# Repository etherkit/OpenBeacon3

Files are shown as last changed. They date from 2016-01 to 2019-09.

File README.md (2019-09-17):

OpenBeacon 3
============
500 mW Si5351C-based MEPT Transmitter

Display
-------
Line 1: GPS status (internal or external antenna, number of satellites fixed), UTC time, transmission mode

Line 2: Frequency

Line 3: PA current, input voltage

Line 4: Message buffer contents

Line 5: Button functions

LEDs
----
* **D1** (red)

    Transmit<br />
    UART TX (during firmware loading)  

* **D2** (green)

    UART RX (during firmware loading)
    
* **D3** (blue)

    PA enabled

* **D5** (yellow)

    Power

User Interface
--------------
* **Tuning**

    Turn S4 rotary encoder to tune
    
* **Tuning Rate**

    Depress rotary encoder shaft momentarily to step through tuning rates. An underline cursor will indicate which frequency digit is being changed.
    
* **Change Band or Mode**

    Hold rotary encoder shaft in for 1 second to access the band and mode change menu. Turn the rotary encoder to cycle between selections. Press button S1 to change the band selection or press button S2 to change the mode selection. Press button S3 to exit this menu.

* **Configuration Menu (S1)**

    Not yet implemented
    
* **Start/Stop (S2)**

    Press button to immediately start a transmission if the transmitter is currently idle, or immediately stop a transmission if one is currently active.
    
* **TX Enb/TX Dis (S3)**

    Press button to toggle the state of recurring transmissions.

Message Buffer System
---------------------
When using the CW, QRSS, DFCW, and Hell modes, five different message buffers are available for transmission. Message Buffer 0 is a special case and consists solely of the value set in the ```callsign``` configuration variable. Message Buffers 1 through 4 can be set to any 40 character (consisting of letters, numbers, or characters ```/```, ```=```, and ```?```) user message via the configuration system. OpenBeacon 2 can be set transmit the contents of any of the five message buffers during a transmit period.

In WSPR mode, OpenBeacon 2 uses the callsign specified in the ```callsign``` configuration variable, the current Maidenhead grid square as determined from GPS (or the default value placed in the ```grid``` configuration variable if the GPS does not have a location fix), and the power level specified in the  ```dbm``` configuration variable.

Recurring Transmissions
-----------------------

Configuration
-------------
The configuration for OpenBeacon 2 is loaded via the included USB-UART bridge. To send configuration data, send OpenBeacon 2 a string consisting of the character 'W', followed by a JSON string setting the desired conifiguration variables, followed by a '@' termination character. For example:

    W{"callsign":"W1AW","default_buffer":2,"msg_mem_2":"HELLO WORLD"}@
    
Here is the list of available configuration variables:

* **default_buffer**
* **msg_mem_1**
* **msg_mem_2**
* **msg_mem_3**
* **msg_mem_4**
* **callsign**
* **grid**
* **dbm**
* **ext_gps_ant**
* **ext_pll_ref**
* **ext_pll_ref_freq**

Required Libraries
------------------
Install these library from the indicated locations before attempting to compile and upload your own firmware.

* Flash Storage [https://github.com/cmaglie/FlashStorage](https://github.com/cmaglie/FlashStorage)
* TinyGPS++ [http://arduiniana.org/libraries/tinygpsplus/](http://arduiniana.org/libraries/tinygpsplus/)
* Etherkit SSD1306 [https://github.com/etherkit/SSD1306-Arduino](https://github.com/etherkit/SSD1306-Arduino)
* Etherkit Si5351 (Library Manager)
* Etherkit JTEncode (Library Manager)
* Scheduler (Library Manager)
* ArduinoJson (Library Manager)
* SPI (Arduino Standard Library)
* Wire (Arduino Standard Library)

Updating the Firmware
---------------------
Connect OpenBeacon 2 to your PC via USB. In the Arduino IDE, select board type ```Arduino/Genuino Zero (Native USB Port)``` and the correct virtual serial port. Sketches can be uploaded to OpenBeacon 2 as if it were a standard Arduino Zero (although a custom hardware configuration is coming soon).

TODO
----
  - [ ] Internal/External Ref Osc
  - [ ] Internal/External GPS Antenna
  - [ ] Get Hell mode working

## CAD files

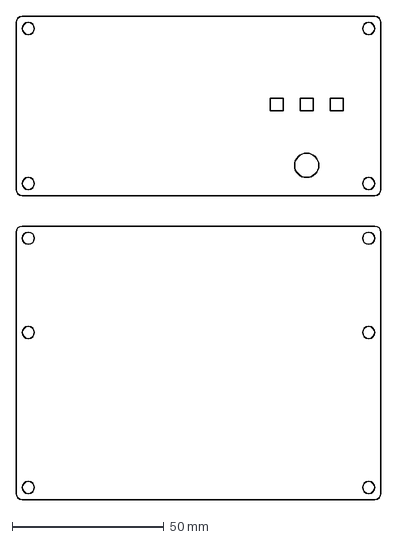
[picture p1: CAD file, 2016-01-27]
enclosure/OpenBeacon2.dxf
120.0 x 159.0 mm

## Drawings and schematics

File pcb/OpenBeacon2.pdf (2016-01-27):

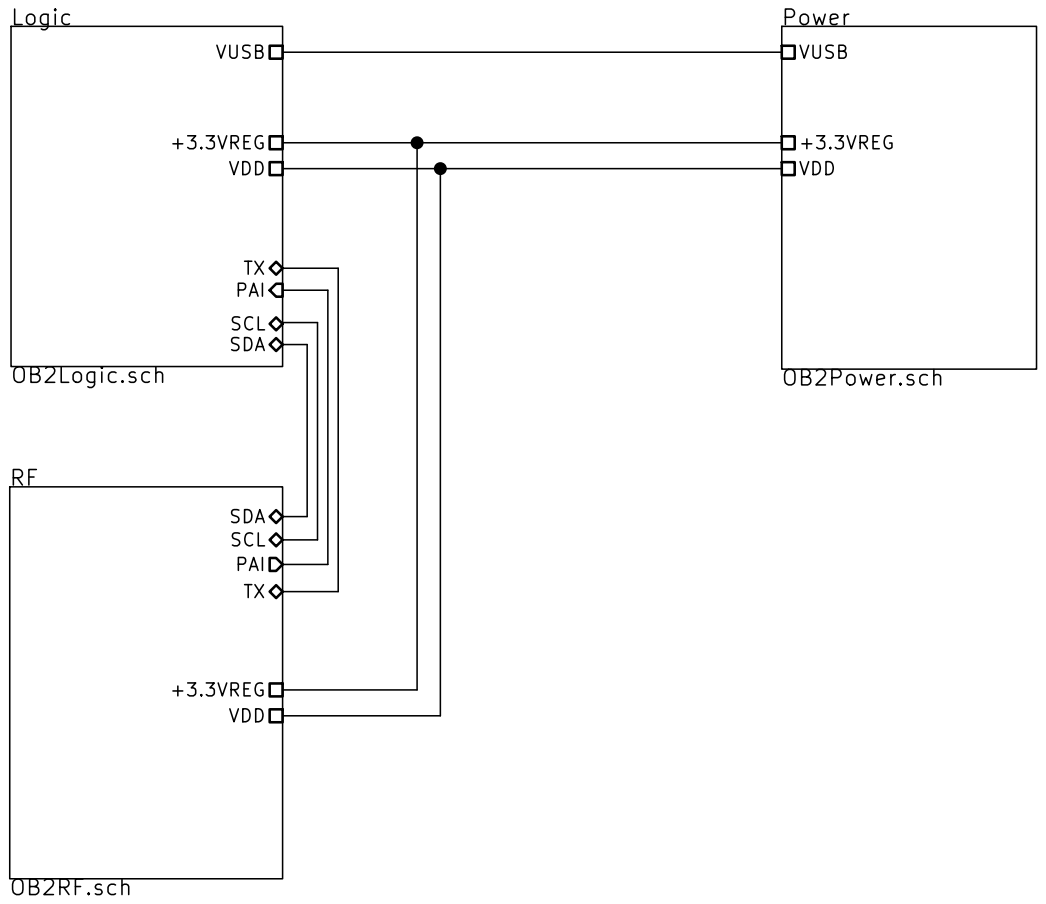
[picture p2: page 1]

File: OpenBeacon2.sch Sheet: / Etherkit Creative Commons License CC-BY-SA

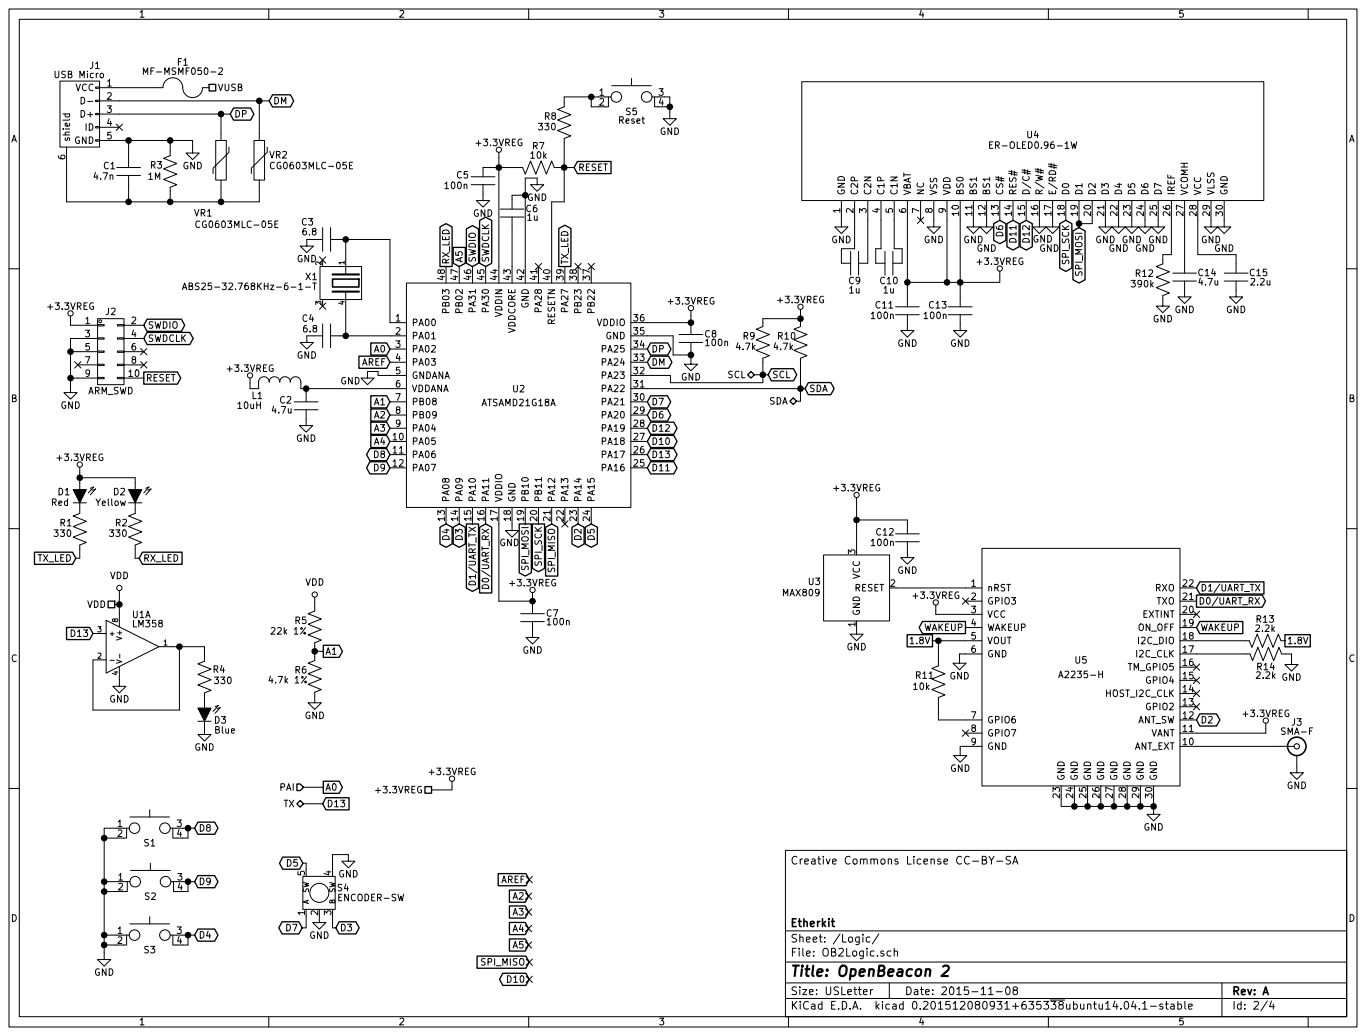
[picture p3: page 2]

9 BS0 10 D2 20 GND 30 BS1 11 D3 21 BS1 12 D4 22 CS# 13 D5 23 RES# 14 D6 24 D/C# 15 D7 25 R/W# 16 IREF 26 E/RD# 17 VCOMH 27 D0 18 VCC 28 D1 19 VLSS 29 U4 ER-OLED0.96-1W

Sheet: /Logic/ Etherkit Creative Commons License CC-BY-SA

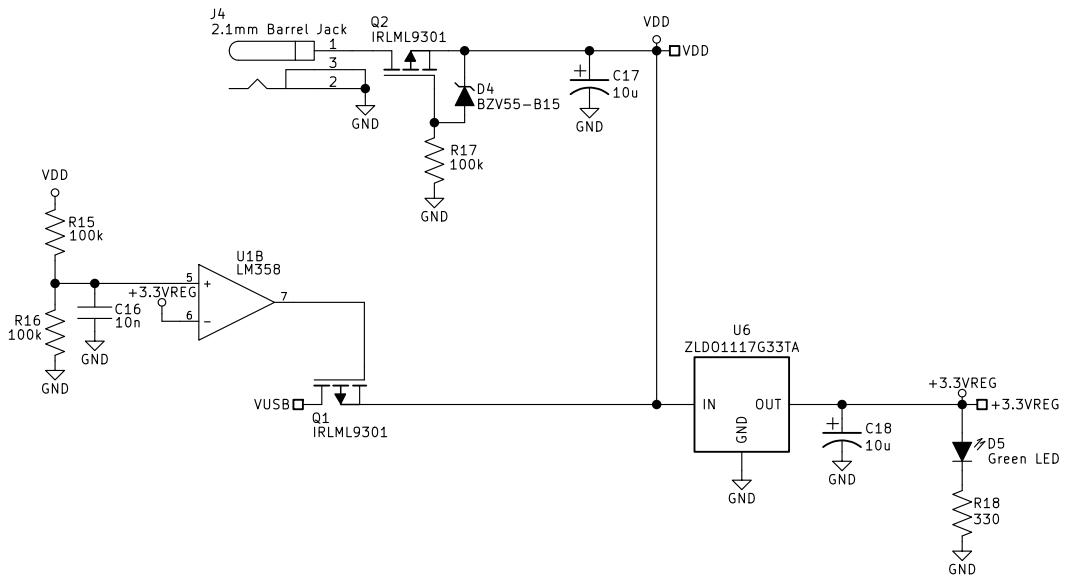
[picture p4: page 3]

File: OB2Power.sch Sheet: /Power/ Etherkit Creative Commons License CC-BY-SA

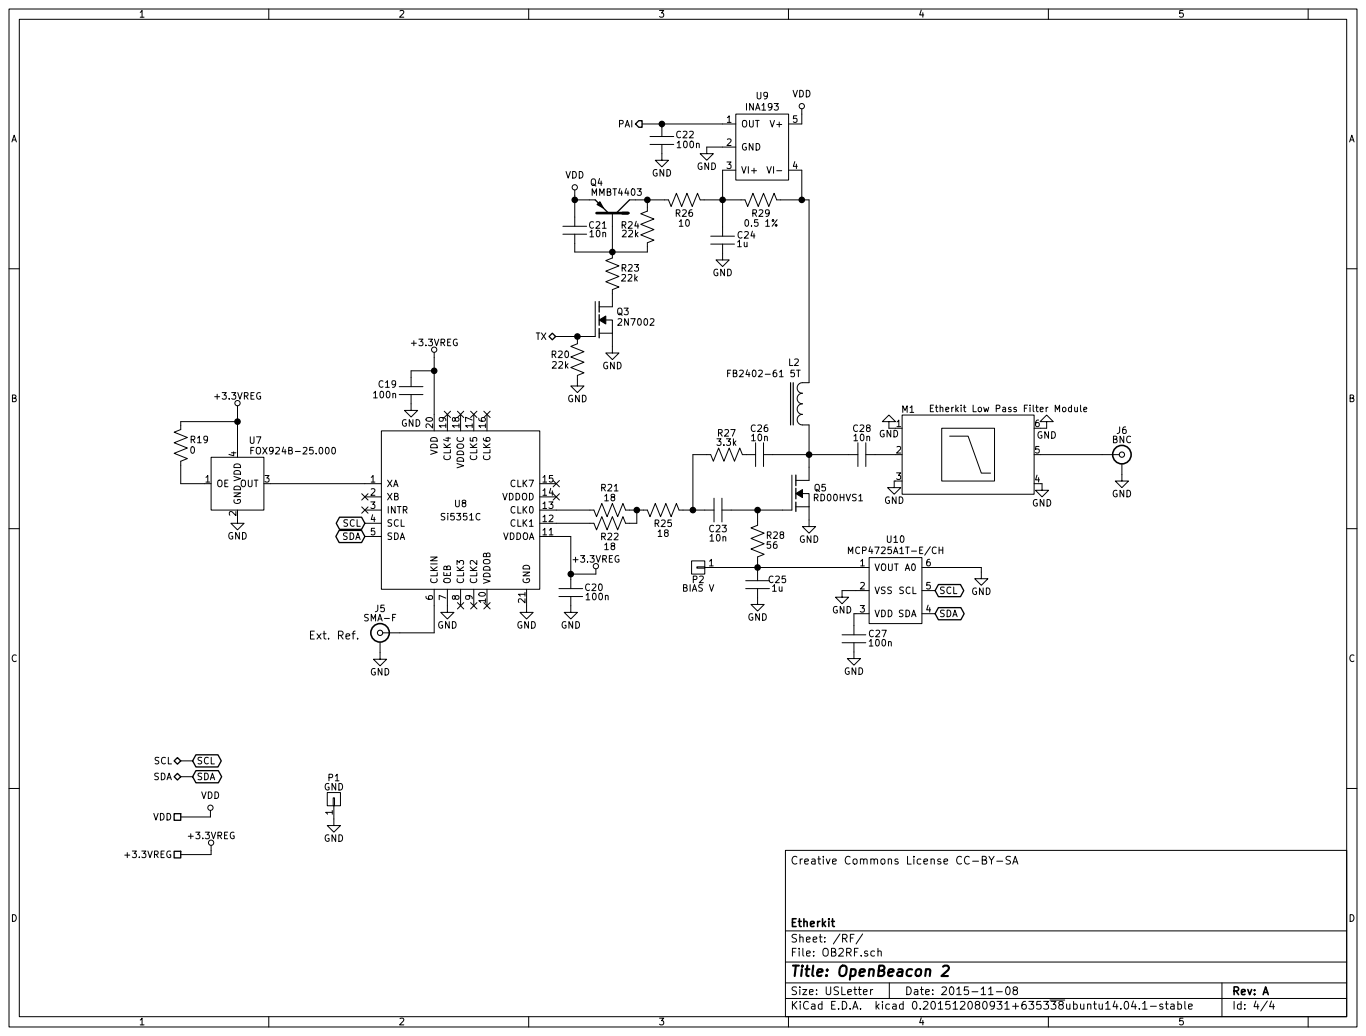
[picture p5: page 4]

9 VDDOB 10 VDD 20 VDDOA 11 GND 21 CLK1 12 CLK0 13 VDDOD 14 CLK7 15 CLK6 16 CLK5 17 VDDOC 18 CLK4 19 U8 Si5351C

File: OB2RF.sch Sheet: /RF/ Etherkit Creative Commons License CC-BY-SA

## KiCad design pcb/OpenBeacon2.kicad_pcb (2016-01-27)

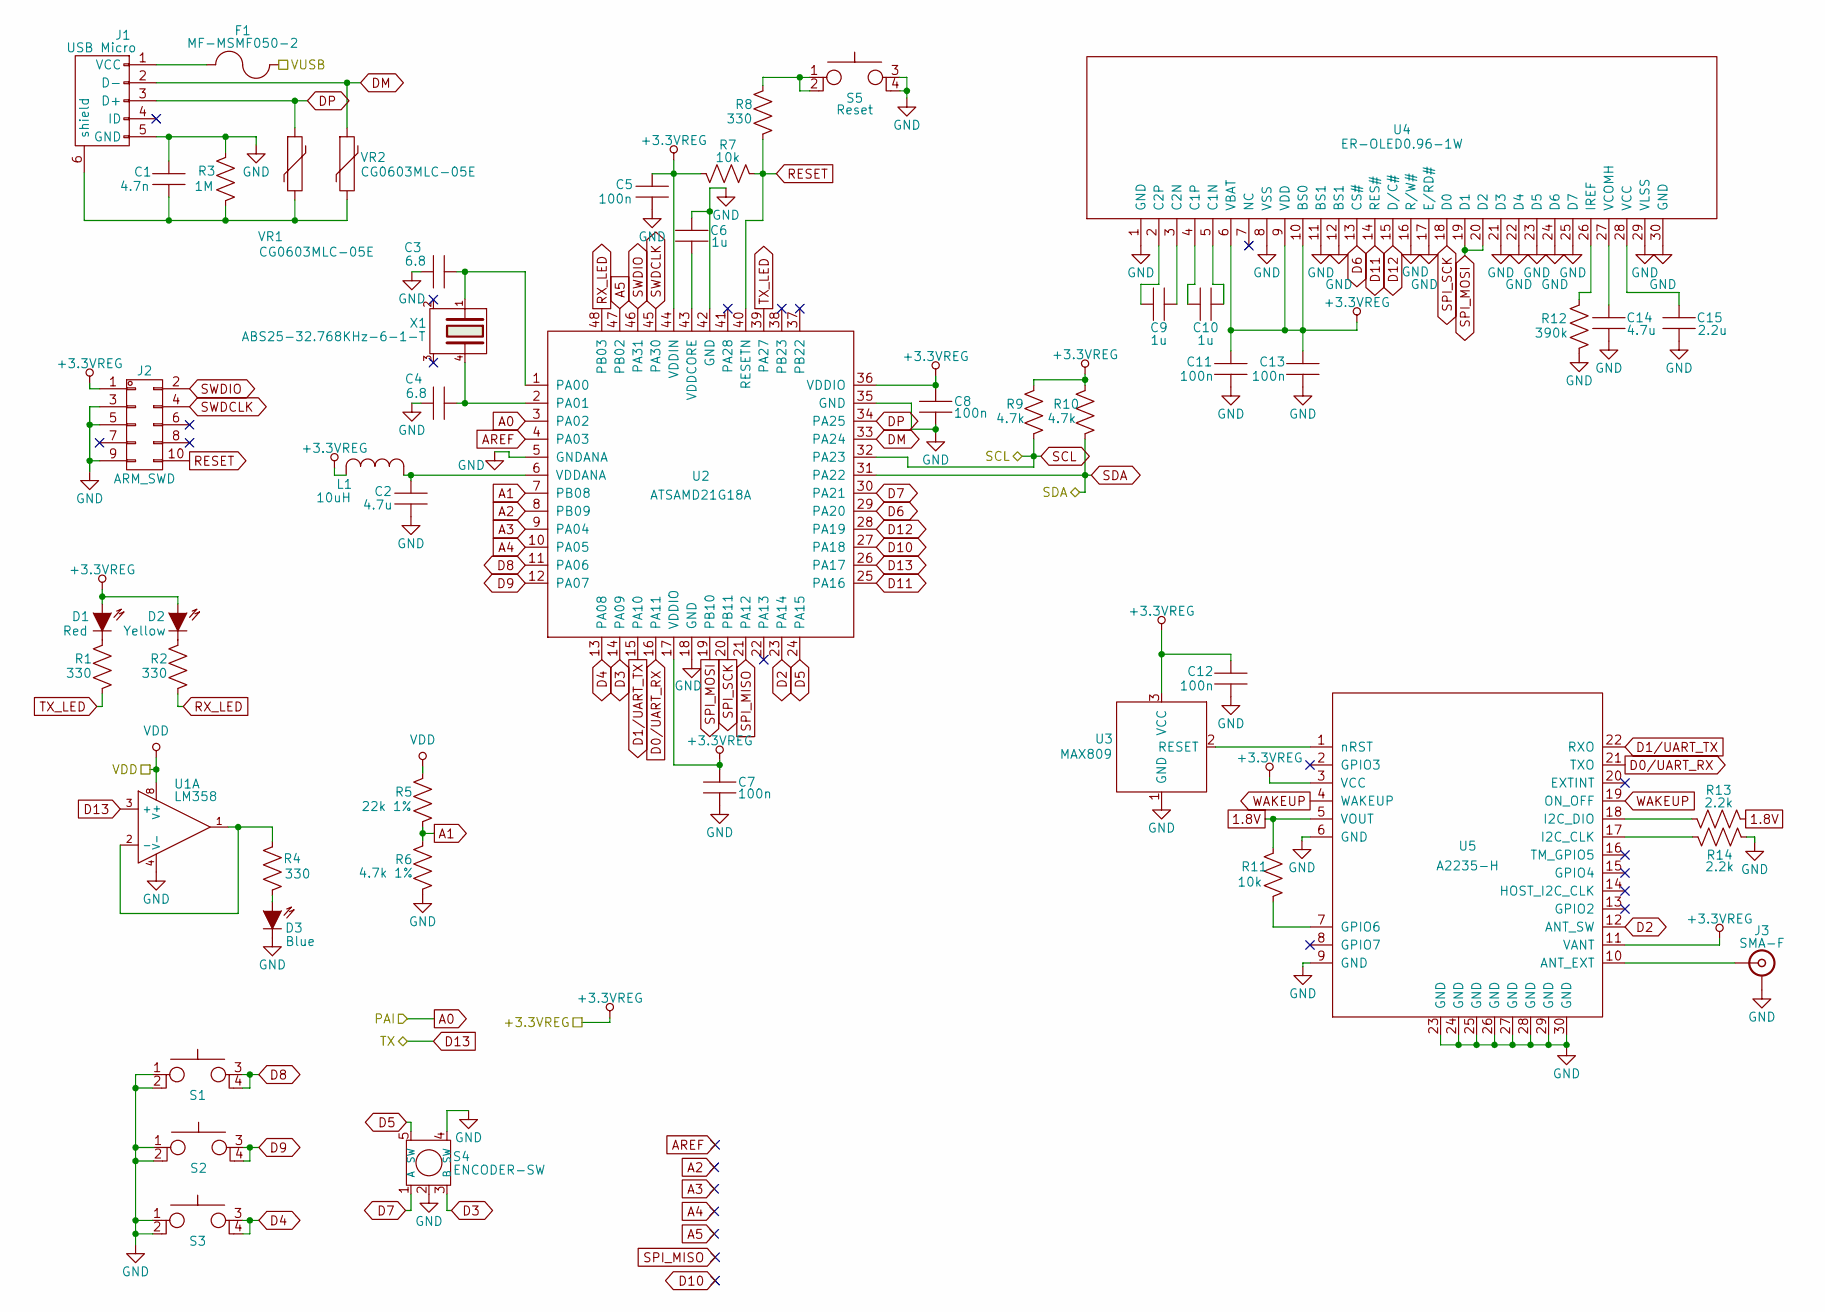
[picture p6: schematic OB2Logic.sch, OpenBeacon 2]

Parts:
C1: 4.7n; C_0805
C2, C14: 4.7u; C_0805
C3, C4: 6.8; C_0805
C5, C7, C8, C11, C12, C13: 100n; C_0805
C6, C9, C10: 1u; C_0805
C15: 2.2u; C_0805
D1: Red; Lite-On_LTST-C170
D2: Yellow; Lite-On_LTST-C170
D3: Blue; Lite-On_LTST-C170
F1: MF-MSMF050-2; Bournes_MF-MSMF050-2
J1: USB Micro; FCI_10118194-0001LF
J2: ARM_SWD; FCI_20021121-00010C4LF
J3: SMA-F; SMA-ENDLAUNCH
L1: 10uH; R_0805
R1, R2, R4, R8: 330; R_0805
R3: 1M; R_0805
R5: 22k 1%; R_0805
R6: 4.7k 1%; R_0805
R7, R11: 10k; R_0805
R9, R10: 4.7k; R_0805
R12: 390k; R_0805
R13, R14: 2.2k; R_0805
S1, S2, S3: Reset; Omron_B3F-1052
S4: ENCODER-SW; Bournes_PEC12R-4225F-S0024
S5: Reset; Alps_SKQGAKE010
U1: LM358; SOIC-8_3.9x4.9mm_Pitch1.27mm
U2: ATSAMD21G18A; TQFP-48_7x7mm_Pitch0.5mm
U3: MAX809; SOT23-MAX809
U4: ER-OLED0.96-1W; EastRising_ER-OLED0.96-1W-Thru
U5: A2235-H
VR1, VR2: CG0603MLC-05E; R_0603
X1: ABS25-32.768KHz-6-1-T; Abracon_ABS25

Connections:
1.8V: R11.1, R13.1, U5.5 (VOUT)
+3.3VREG: C5.1, C7.1, C8.1, C11.1, C12.1, C13.1, D1.1 (A), D2.1 (A), J2.1, L1.1, R7.2, R9.1, R10.1, U2.17 (VDDIO), U2.36 (VDDIO), U2.44 (VDDIN), U3.3 (VCC), U4.6 (VBAT), U4.9 (VDD), U4.10 (BS0), U5.3 (VCC), U5.11 (VANT); also elsewhere on the board
/Logic/VUSB: F1.2; also elsewhere on the board
A0: U2.3 (PA02); also elsewhere on the board
A1: R5.2, R6.1, U2.7 (PB08)
A2: U2.8 (PB09)
A3: U2.9 (PA04)
A4: U2.10 (PA05)
A5: U2.47 (PB02)
AREF: U2.4 (PA03)
D0/UART_RX: U2.16 (PA11), U5.21 (TXO)
D1/UART_TX: U2.15 (PA10), U5.22 (RXO)
D2: U2.23 (PA14), U5.12 (ANT_SW)
D3: S4.3 (B), U2.14 (PA09)
D4: S3.3, S3.4, U2.13 (PA08)
D5: S4.5 (SW), U2.24 (PA15)
D6: U2.29 (PA20), U4.13 (CS#)
D7: S4.1 (A), U2.30 (PA21)
D8: S1.3, S1.4, U2.11 (PA06)
D9: S2.3, S2.4, U2.12 (PA07)
D10: U2.27 (PA18)
D11: U2.25 (PA16), U4.14 (RES#)
D12: U2.28 (PA19), U4.15 (D/C#)
D13: U1.3 (+), U2.26 (PA17); also elsewhere on the board
DM: J1.2 (D-), U2.33 (PA24), VR2.1
DP: J1.3 (D+), U2.34 (PA25), VR1.1
GND: C1.1, C2.2, C3.1, C4.1, C5.2, C6.1, C7.2, C8.2, C11.2, C12.2, C13.2, C14.2, C15.2, D3.2 (K), J1.5 (GND), J2.3, J2.5, J2.9, J3.2 (Ext), R3.1, R6.2, R12.2, R14.1, S1.1, S1.2, S2.1, S2.2, S3.1, S3.2, S4.2, S4.4 (SW), S5.3, S5.4, U1.4 (V-), U2.5 (GNDANA), U2.18 (GND), U2.35 (GND), U2.42 (GND), U3.1 (GND), U4.1 (GND), U4.8 (VSS), U4.11 (BS1), U4.12 (BS1), U4.16 (R/W#), U4.17 (E/RD#), U4.21 (D3), U4.22 (D4), U4.23 (D5), U4.24 (D6), U4.25 (D7), U4.29 (VLSS), U4.30 (GND), U5.6 (GND), U5.9 (GND), U5.23 (GND), U5.24 (GND), U5.25 (GND), U5.26 (GND), U5.27 (GND), U5.28 (GND), U5.29 (GND), U5.30 (GND); also elsewhere on the board
unnamed: C1.2, J1.6 (shield), R3.2, VR1.2, VR2.2
unnamed: C2.1, L1.2, U2.6 (VDDANA)
unnamed: C3.2, U2.1 (PA00), X1.1
unnamed: C4.2, U2.2 (PA01), X1.4
unnamed: C6.2, U2.43 (VDDCORE)
unnamed: C9.1, U4.2 (C2P)
unnamed: C9.2, U4.3 (C2N)
unnamed: C10.1, U4.4 (C1P)
unnamed: C10.2, U4.5 (C1N)
unnamed: C14.1, U4.27 (VCOMH)
unnamed: C15.1, U4.28 (VCC)
unnamed: D1.2 (K), R1.1
unnamed: D2.2 (K), R2.1
unnamed: D3.1 (A), R4.2
unnamed: F1.1, J1.1 (VCC)
unnamed: J3.1 (In), U5.10 (ANT_EXT)
unnamed: R4.1, U1.1, U1.2 (-)
unnamed: R8.1, S5.1, S5.2
unnamed: R11.2, U5.7 (GPIO6)
unnamed: R12.1, U4.26 (IREF)
unnamed: R13.2, U5.18 (I2C_DIO)
unnamed: R14.2, U5.17 (I2C_CLK)
unnamed: U3.2 (RESET), U5.1 (nRST)
RESET: J2.10, R7.1, R8.2, U2.40 (RESETN)
RX_LED: R2.2, U2.48 (PB03)
SCL: R9.2, U2.32 (PA23); also elsewhere on the board
SDA: R10.2, U2.31 (PA22); also elsewhere on the board
SPI_MISO: U2.21 (PA12)
SPI_MOSI: U2.19 (PB10), U4.19 (D1), U4.20 (D2)
SPI_SCK: U2.20 (PB11), U4.18 (D0)
SWDCLK: J2.4, U2.45 (PA30)
SWDIO: J2.2, U2.46 (PA31)
TX_LED: R1.2, U2.39 (PA27)
VDD: R5.1, U1.8 (V+); also elsewhere on the board
WAKEUP: U5.4 (WAKEUP), U5.19 (ON_OFF)

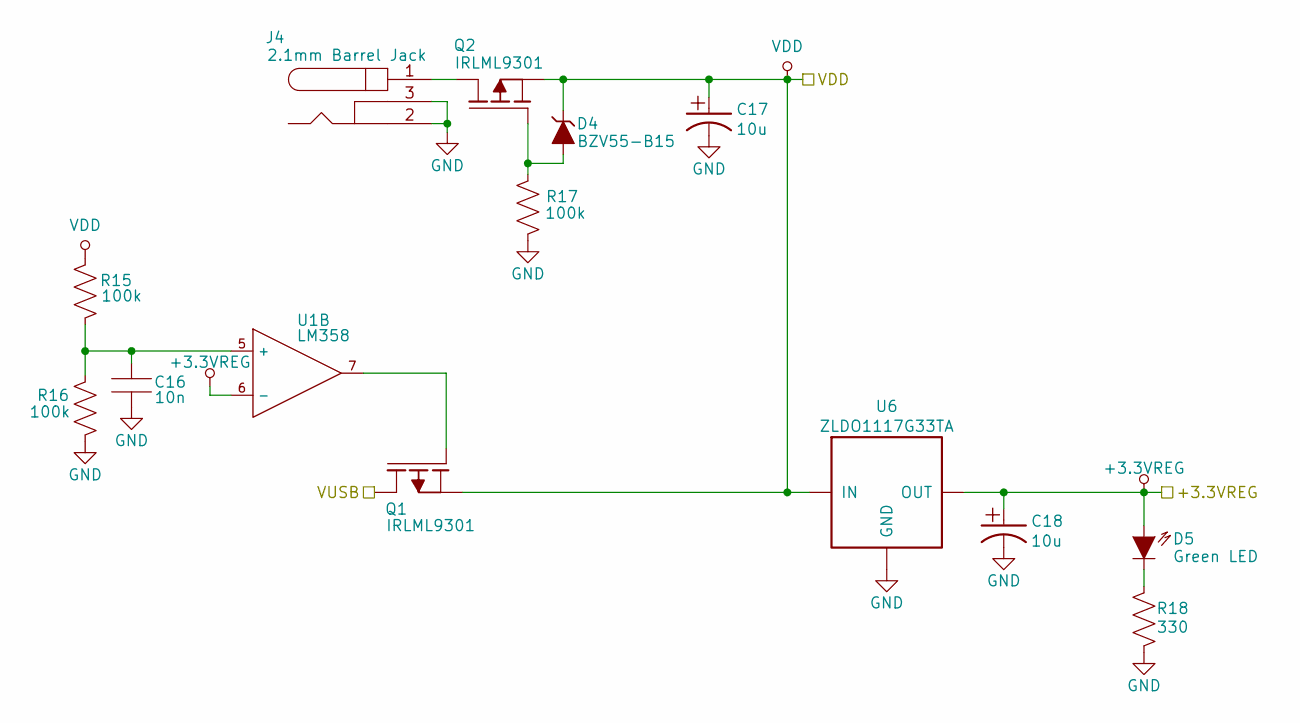
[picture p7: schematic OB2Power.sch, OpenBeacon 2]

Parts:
C16: 10n; C_0805
C17, C18: 10u; CAP-ELEC-5MM
D4: BZV55-B15; SOD80
D5: Green LED; Lite-On_LTST-C170
J4: 2.1mm Barrel Jack; DCPOWER-KOBICONN-163-7620-E
Q1, Q2: IRLML9301; SOT23-2N7002
R15, R16, R17: 100k; R_0805
R18: 330; R_0805
U1: LM358; SOIC-8_3.9x4.9mm_Pitch1.27mm
U6: ZLDO1117G33TA; SOT-223-3

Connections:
+3.3VREG: C18.1, D5.1 (A), U1.6 (-), U6.1 (OUT); also elsewhere on the board
/Logic/VUSB: Q1.3 (D); also elsewhere on the board
GND: C16.2, C17.2, C18.2, J4.2, J4.3, R16.2, R17.2, R18.2, U6.2 (GND); also elsewhere on the board
unnamed: C16.1, R15.2, R16.1, U1.5 (+)
unnamed: D4.1 (A), Q2.2 (G), R17.1
unnamed: D5.2 (K), R18.1
unnamed: J4.1, Q2.3 (D)
unnamed: Q1.2 (G), U1.7
VDD: C17.1, D4.2 (K), Q1.1 (S), Q2.1 (S), R15.1, U6.3 (IN); also elsewhere on the board

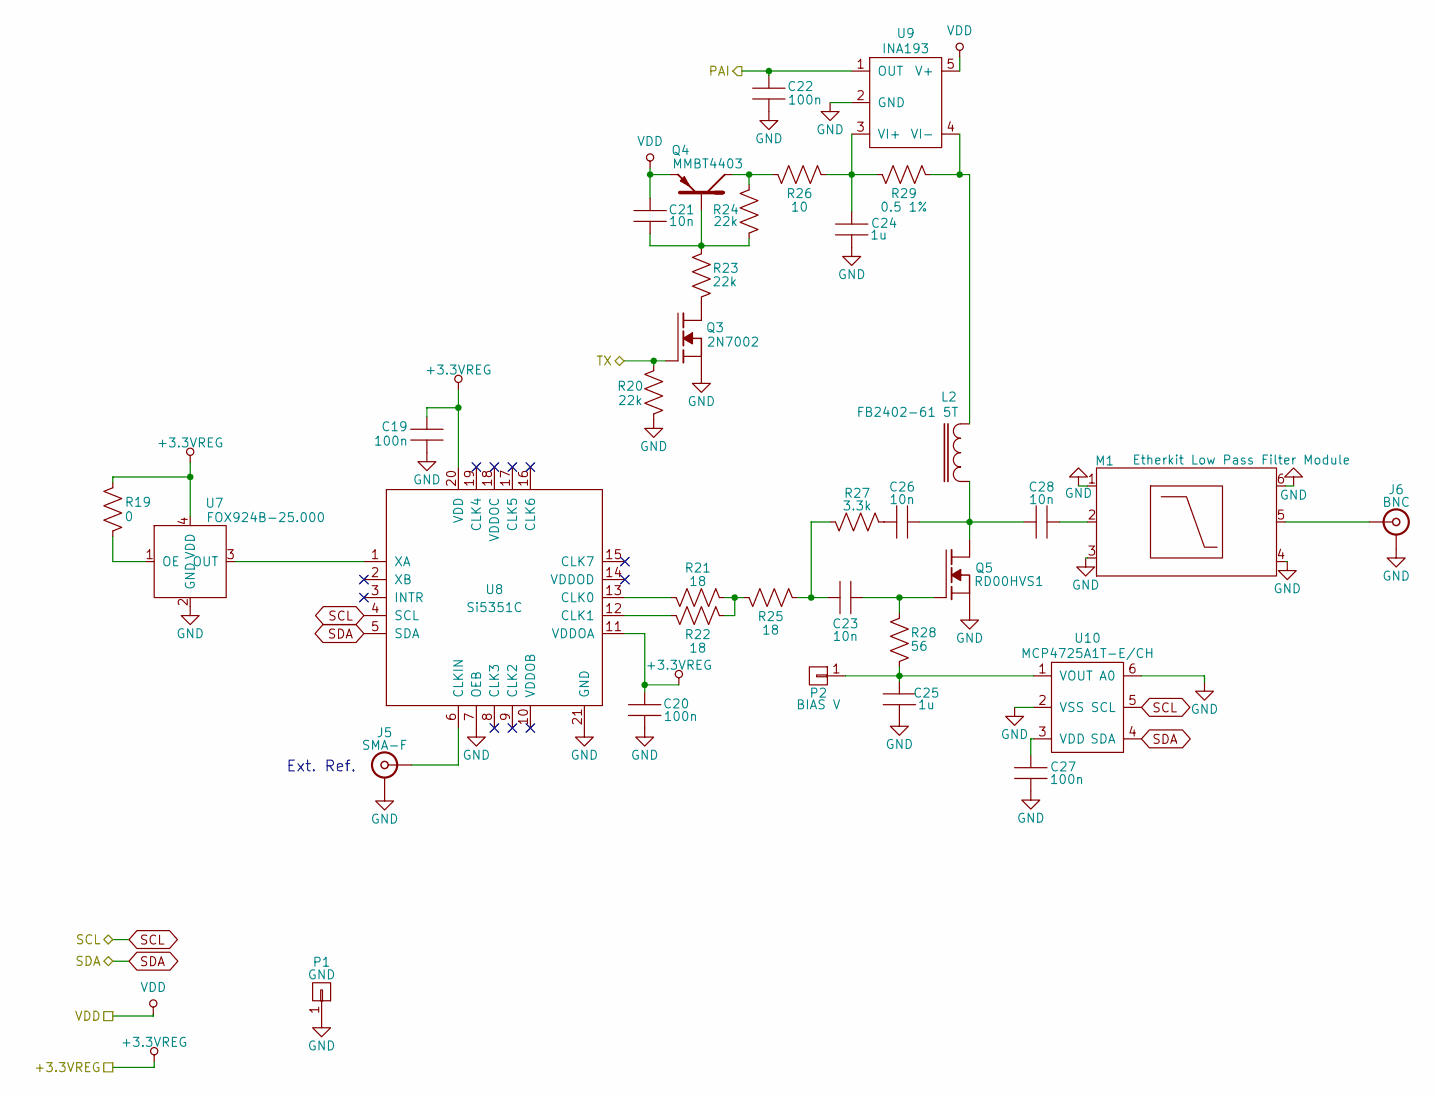
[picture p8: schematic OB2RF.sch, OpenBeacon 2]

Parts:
C19, C20, C22, C27: 100n; C_0805
C21, C23, C26, C28: 10n; C_0805
C24, C25: 1u; C_0805
J5: SMA-F; SMA-ENDLAUNCH
J6: BNC; BNC-AMPHENOL-31-5431-10RFX
L2: FB2402-61 5T; BN2402-H
M1: Etherkit Low Pass Filter Module; LPFModule
P1: GND; Measurement_Point_Square-TH_Small
P2: BIAS V; Measurement_Point_Square-TH_Small
Q3: 2N7002; SOT23-2N7002
Q4: MMBT4403; SOT23-MMBT440X
Q5: RD00HVS1
R19: 0; R_0805
R20, R23, R24: 22k; R_0805
R21, R22, R25: 18; R_0805
R26: 10; R_0805
R27: 3.3k; R_0805
R28: 56; R_0805
R29: 0.5 1%; R_0805
U7: FOX924B-25.000; Fox_924B
U8: Si5351C; QFN-20-1EP_4x4mm_Pitch0.5mm
U9: INA193; SOT23-5
U10: MCP4725A1T-E/CH; SOT23-6

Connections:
+3.3VREG: C19.1, C20.1, R19.1, U7.4 (VDD), U8.11 (VDDOA), U8.20 (VDD); also elsewhere on the board
A0: C22.1, U9.1 (OUT); also elsewhere on the board
D13: Q3.2 (G), R20.1; also elsewhere on the board
GND: C19.2, C20.2, C22.2, C24.2, C25.2, C27.2, J5.2 (Ext), J6.2 (Ext), M1.1, M1.3, M1.4, M1.6, P1.1, Q3.1 (S), Q5.1 (S), R20.2, U7.2 (GND), U8.7 (OEB), U8.21 (GND), U9.2 (GND), U10.2 (VSS), U10.6 (A0); also elsewhere on the board
unnamed: C21.2, Q4.2 (B), R23.1, R24.2
unnamed: C23.1, Q5.2 (G), R28.1
unnamed: C23.2, R25.1, R27.2
unnamed: C24.1, R26.1, R29.2, U9.3 (VI+)
unnamed 43: C25.1, P2.1, R28.2, U10.1 (VOUT); also elsewhere on the board
unnamed: C26.1, C28.2, L2.2, Q5.3 (D)
unnamed: C26.2, R27.1
unnamed: C27.1, U10.3 (VDD)
unnamed: C28.1, M1.2
unnamed: J5.1 (In), U8.6 (CLKIN)
unnamed: J6.1 (In), M1.5
unnamed: L2.1, R29.1, U9.4 (VI-)
unnamed: Q3.3 (D), R23.2
unnamed: Q4.3 (C), R24.1, R26.2
unnamed: R19.2, U7.1 (OE)
unnamed: R21.1, R22.1, R25.2
unnamed: R21.2, U8.13 (CLK0)
unnamed: R22.2, U8.12 (CLK1)
unnamed: U7.3 (OUT), U8.1 (XA)
SCL: U8.4 (SCL), U10.5 (SCL); also elsewhere on the board
SDA: U8.5 (SDA), U10.4 (SDA); also elsewhere on the board
VDD: C21.1, Q4.1 (E), U9.5 (V+); also elsewhere on the board

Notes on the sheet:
Ext. Ref.

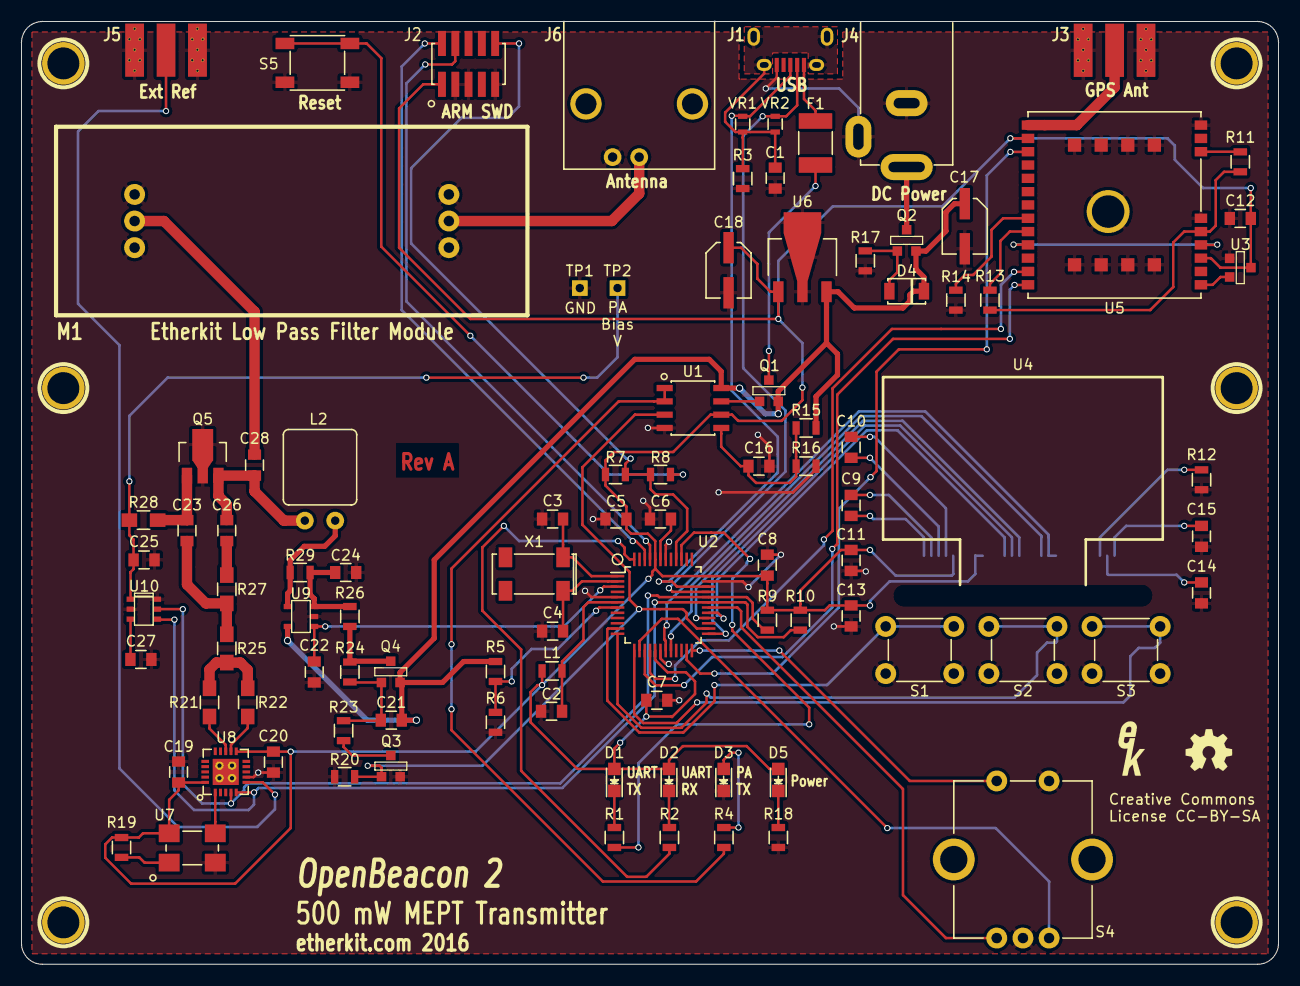
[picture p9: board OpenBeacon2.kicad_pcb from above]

Board: 2 copper layers, 120.0 x 90.0 mm, 104 parts (0 on the bottom side), 79 nets.

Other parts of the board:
1PIN, 1PIN#2, 1PIN#3, 1PIN#4, 1PIN#5, 1PIN#6: P***; MOUNTINGHOLE-4MM
Ref**: Val**; EtherkitLogoSmall
TP1: GND; Measurement_Point_Square-TH_Small
TP2: BIAS V; Measurement_Point_Square-TH_Small

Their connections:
GND: TP1.1; also elsewhere on the board
unnamed 43: TP2.1; also elsewhere on the board

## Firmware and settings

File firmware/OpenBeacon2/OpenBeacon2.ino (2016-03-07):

// Hardware Requirements
// ---------------------
// This firmware must be run on an Arduino Zero capable microcontroller
//
// Required Libraries
// ------------------
// Flash Storage (https://github.com/cmaglie/FlashStorage)
// TinyGPS++ (http://arduiniana.org/libraries/tinygpsplus/)
// Etherkit SSD1306 (https://github.com/etherkit/SSD1306-Arduino)
// Etherkit Si5351 (Library Manager)
// Etherkit JTEncode (Library Manager)
// Scheduler (Library Manager)
// ArduinoJson (Library Manager)
// SPI (Arduino Standard Library)
// Wire (Arduino Standard Library)

#include <ArduinoJson.h>
#include <FlashStorage.h>
#include <Scheduler.h>
#include <JTEncode.h>
#include <TinyGPS++.h>
#include <SPI.h>
#include <Wire.h>
#include <SSD1306.h>
#include <si5351.h>
#include <stdint.h>
#include <string.h>

#include "morsechar.h"
#include "modes.h"
#include "font.h"
#include "bands.h"

// Class instantiation
SSD1306 ssd1306;
Si5351 si5351;
TinyGPSPlus gps;
JTEncode jtencode;

// Hardware defines
#define GPS_ANT                  2
#define ENC_A                    7
#define ENC_B                    3
#define ENC_BTN                  5
#define BTN_S1                   8
#define BTN_S2                   9
#define BTN_S3                   4
#define REFCLK                   10
#define TX_KEY                   13
#define TXI                      A0
#define VCC                      A1

// Default defines
#define DEFAULT_DFCW_OFFSET       5
#define DEFAULT_WPM               35000
#define DEFAULT_MSG_DELAY         10            // in minutes
#define DEFAULT_MODE              MODE_WSPR
#define DEFAULT_BAND              3             // 30 meters
#define DEFAULT_CALLSIGN          "LA3PNA"
#define DEFAULT_GRID              "JO59BR"
#define DEFAULT_MSG_1             "OpenBeacon2"
#define DEFAULT_MSG_2             "MSG2"
#define DEFAULT_MSG_3             "MSG3"
#define DEFAULT_MSG_4             "MSG4"
#define DEFAULT_SI5351_INT_CORR   0
#define DEFAULT_SI5351_EXT_CORR   0
#define DEFAULT_EXT_GPS_ANT       false
#define DEFAULT_EXT_PLL_REF       false
#define DEFAULT_EXT_PLL_REF_FREQ  25000000UL
#define DEFAULT_DBM               27

// Mode defines
#define MULT_DAH                 3           // DAH is 3x a DIT
#define MULT_WORDDELAY           7           // Space between words is 7 dits
#define MULT_HELL_WORDDELAY      200
#define MULT_HELL_CHARDELAY      20
#define MULT_HELL_GLYPHDELAY     60
#define HELL_ROW_RPT             3
//#define WSPR_OFFSET              146

// Other defines
#define MCP4725A1_BUS_BASE_ADDR  0x62
#define MCP4725A1_VREF           3300UL
#define ANALOG_REF               3300UL
#define PA_BIAS_FULL             2750UL
#define PA_MAX_CURRENT           200
#define GPS_DEBUG                0


// Enumerations
enum BUFFER {BUFFER_0, BUFFER_1, BUFFER_2, BUFFER_3, BUFFER_4};
enum STATE {STATE_IDLE, STATE_DIT, STATE_DAH, STATE_DITDELAY, STATE_DAHDELAY, STATE_WORDDELAY, 
  STATE_MSGDELAY, STATE_EOMDELAY, STATE_CHARDELAY, STATE_HELLCOL, STATE_HELLROW, STATE_CAL, STATE_FSK, 
  STATE_WSPR_INIT, STATE_PREAMBLE, STATE_HELLIDLE};
enum MENU {MENU_MAIN, MENU_BAND, MENU_MODE};

// Structs
typedef struct
{
  boolean valid;
  uint8_t version_major;
  uint8_t version_minor;
  enum MODE mode;
  uint8_t band;
  uint16_t wpm;
  uint8_t msg_delay;
  uint8_t dfcw_offset;
  enum BUFFER buffer;
  char callsign[20];
  char grid[10];
  char msg_mem_1[MSG_BUFFER_SIZE];
  char msg_mem_2[MSG_BUFFER_SIZE];
  char msg_mem_3[MSG_BUFFER_SIZE];
  char msg_mem_4[MSG_BUFFER_SIZE];
  int32_t si5351_int_corr;
  int32_t si5351_ext_corr;
  boolean ext_gps_ant;
  boolean ext_pll_ref;
  uint32_t ext_pll_ref_freq;
  uint8_t dbm; 
} Config;

// Instantiate flash storage
FlashStorage(flash_store, Config);
Config flash_config;

// Interrupt service routine variables
volatile boolean A_set = true;
volatile boolean B_set = false;
//volatile unsigned long frequency = 10000000UL; // Startup frequency
//volatile unsigned long frequency = 7040057UL; // 40m WSPR
//volatile unsigned long frequency = 14097057UL; // 20m WSPR
//volatile unsigned long frequency = 21096073UL; // 20m WSPR
//volatile unsigned long frequency = 14078600UL; // 20m JT9
//volatile unsigned long frequency = 14077500UL; // 20m JT65
//volatile unsigned long frequency = 14077500UL; // 20m JT4
//volatile unsigned long frequency = 50294444UL; // Startup frequency
//volatile unsigned long frequency = 10139973UL; // 30m QRSS
volatile unsigned long frequency = 10140123UL; // 30m WSPR
volatile unsigned long last_reported_pos;   // change management
volatile static boolean rotating = false;    // debounce management
volatile uint32_t timer, cur_timer;
volatile boolean toggle = false;

// Global variables
int32_t corr; // this is the correction factor for the Si5351, use calibration sketch to find value.
unsigned int tune_step = 0; // This is in 10^tune_step Hz
uint8_t tx_current;
uint32_t current_a[6];
uint16_t supply_voltage;
uint32_t dit_length;
enum MODE cur_mode;
enum STATE cur_state, next_state;
uint32_t cur_state_end, msg_delay_end;
char msg_buffer[220];
char display_buffer[22];
//char symbol_buffer[220];
char * cur_msg_p;
char * cur_glyph_p;
uint8_t cur_character = '\0';
uint8_t cur_hell_char = '\0';
uint8_t cur_hell_col = 0;
uint8_t cur_hell_row = 0;
uint16_t wpm;
uint8_t msg_delay;
enum BUFFER cur_buffer;
uint8_t dfcw_offset;
boolean tx;
boolean pa_enable;
boolean tx_lock = false;
boolean tx_enable = false;
boolean ext_gps_ant = false;
boolean ext_pll_ref = false;
char callsign[20];
char grid[10];
uint8_t dbm;
enum MENU cur_menu;
uint8_t cur_band;

// EEPROM variables
/*
uint8_t ee_osc;
uint8_t	ee_mode = DEFAULT_MODE;
uint16_t ee_wpm = DEFAULT_WPM;
uint8_t ee_msg_delay = DEFAULT_MSG_DELAY;
uint8_t ee_dfcw_offset = DFCW_DEFAULT_OFFSET;
uint8_t ee_msg_mem_1[MSG_BUFFER_SIZE] = "NT7S";
uint8_t ee_msg_mem_2[MSG_BUFFER_SIZE] = "MSG2";
uint8_t ee_msg_mem_3[MSG_BUFFER_SIZE] = "MSG3";
uint8_t ee_msg_mem_4[MSG_BUFFER_SIZE] = "MSG4";
uint8_t ee_wspr_symbols[WSPR_BUFFER_SIZE] = "";
uint8_t ee_buffer = BUFFER_1;
uint8_t ee_glyph_1[GLYPH_SIZE] = {0x7F, 0x7F, 0x7F, 0x7F, 0x7F, 0x7F, 0x7F, 0x7F, 0x7F, 0x7F, 0x7F, 0x7F, 0x7F, 0x7F, 0x7F, 0x7F, 0x7F, 0x7F, 0x7F, 0x7F, 0x80};
uint8_t ee_glyph_2[GLYPH_SIZE] = {0x1C, 0x3E, 0x7F, 0x7F, 0x7F, 0x3E, 0x1C, 0x80};
uint8_t ee_glyph_3[GLYPH_SIZE] = "";
uint8_t ee_glyph_4[GLYPH_SIZE] = "";
*/

// Interrupt on A changing state
void do_encoder_A(void)
{
  // debounce
  if(rotating) 
  {
    //delay(1);  // wait a little until the bouncing is done
  }

  // Test transition, did things really change?
  if(digitalRead(ENC_A) != A_set)
  { // debounce once more
    A_set = !A_set;
    // adjust counter + if A leads B
    if(A_set && !B_set)
    {
      switch(cur_menu)
      {
      case MENU_MAIN:
        if(!tx_lock)
        {
          frequency += power_10(tune_step);
        }
        break;
      case MENU_BAND:
        cur_band++;
        if(cur_band >= BAND_COUNT)
        {
          cur_band = 0;
        }
        // Tune to new band
        frequency = band_table[cur_band].wspr;
        break;
      case MENU_MODE:
        cur_mode = (enum MODE)(cur_mode + 1);
        if(cur_mode >= MODE_COUNT)
        {
          cur_mode = (enum MODE)0;
        }
        break;
      }
      rotating = false;  // no more debouncing until loop() hits again
    }
  }
}

// Interrupt on B changing state, same as A above
void do_encoder_B(void)
{
  if(rotating)
  {
    //delay(1);
  }

  if(digitalRead(ENC_B) != B_set)
  {
    B_set = !B_set;
    //  adjust counter - 1 if B leads A
    if(B_set && !A_set)
    {
      switch(cur_menu)
      {
      case MENU_MAIN:
        if(!tx_lock)
        {
          frequency -= power_10(tune_step);
        }
        break;
      case MENU_BAND:
        if(cur_band == 0)
        {
          cur_band = BAND_COUNT - 1;
        }
        else
        {
          cur_band--;
        }
        // Tune to new band
        frequency = band_table[cur_band].wspr;
        break;
      case MENU_MODE:
        if(cur_mode == 0)
        {
          cur_mode = (enum MODE)(MODE_COUNT - 1);
          
        }
        else
        {
          cur_mode = (enum MODE)(cur_mode - 1);
        }
        break;
      }
      rotating = false;
    }
  }
}

// TODO: probably delete
void update_timer(void)
{
  // Latch the current time
  // MUST disable interrupts during this read or there will be an occasional corruption of cur_timer
  noInterrupts();
  cur_timer = millis();
  interrupts();
  yield();
}

unsigned long power_10(unsigned long exponent)
{
  // bounds checking pls
  if(exponent == 0)
  {
    return 1;
  }
  else
  {
    return 10 * power_10(exponent - 1);
  }
}

void print_freq(uint8_t y, unsigned long freq)
{
  // We will print out the frequency as a fixed length string and pad if less than 100s of MHz
  char temp_str[6];
  int zero_pad = 0;
  uint8_t underline;
  
  // MHz
  yield();
  if(freq / 1000000UL > 0)
  {
    sprintf(temp_str, "%3lu", freq / 1000000UL);
    zero_pad = 1;
  }
  else
  {
    sprintf(temp_str, "   ");
  }
  ssd1306.text(0, y, TEXT_FONT_11X21, false, temp_str);
  freq %= 1000000UL;
  
  // kHz
  yield();
  if(zero_pad == 1)
  {
    sprintf(temp_str, "%03lu", freq / 1000UL);
  }
  else if(freq / 1000UL > 0)
  {
    sprintf(temp_str, "%3lu", freq / 1000UL);
    zero_pad = 1;
  }
  else
  {
    sprintf(temp_str, "   ");
  }
  ssd1306.text(41, y, TEXT_FONT_11X21, false, temp_str);
  freq %= 1000UL;
  
  // Hz
  yield();
  if(zero_pad == 1)
  {
    sprintf(temp_str, "%03lu", freq);
  }
  else
  {
    sprintf(temp_str, "%3lu", freq);
  }
  ssd1306.text(83, y, TEXT_FONT_11X21, false, temp_str);
  
  // Indicate step size
  yield();
  switch(tune_step)
  {
  case 5:
    underline = 41;
    break;
  case 4:
    underline = 53;
    break;
  case 3:
    underline = 65;
    break;
  case 2:
    underline = 83;
    break;
  case 1:
    underline = 95;
    break;
  case 0:
    underline = 107;
    break;
  }

  yield();
  ssd1306.hline(y + 21, underline, underline + 11, PIXEL_WHITE);
  ssd1306.hline(y + 22, underline, underline + 11, PIXEL_WHITE);
  
  // Underline it all
  ssd1306.hline(y + 24, 0, 127, PIXEL_WHITE);
}

// Voltage specified in millivolts
void set_pa_bias(uint16_t voltage)
{
  uint32_t reg;
  uint8_t reg1, reg2;
  
  // Bounds checking
  if(voltage > MCP4725A1_VREF)
  {
    voltage = MCP4725A1_VREF;
  }
  
  // Convert millivolts to the correct register value
  reg = ((uint32_t)voltage * 4096UL) / MCP4725A1_VREF;
  reg1 = (uint8_t)((reg >> 8) & 0xFF);
  reg2 = (uint8_t)(reg & 0xFF); 
  
  // Write the register to the MCP4725A1
  Wire.beginTransmission(MCP4725A1_BUS_BASE_ADDR);
  Wire.write(reg1);
  Wire.write(reg2);
  Wire.endTransmission();
}
// Return value in milliamps
uint8_t get_tx_current(void)
{
  uint32_t txi_adc;
  uint32_t temp = 0;
  // Get raw ADC reading from the current shunt
 txi_adc = analogRead(TXI);
  
  // Convert 10-bit ADC reading to milliamps
  //return (txi_adc * ANALOG_REF / 1024UL) / 10UL; // 10-bit ADC, shunt res. is 0.5 ohm, amp is x20

  // Convert 12-bit ADC reading to milliamps
 // return (txi_adc * ANALOG_REF / 4096UL) / 10UL; // 10-bit ADC, shunt res. is 0.5 ohm, amp is x20
uint32_t tempcur = (txi_adc * ANALOG_REF / 4096UL) / 10UL; // 10-bit ADC, shunt res. is 0.5 ohm, amp is x20

  for (int i=4; i>=0; i--) // should probably use memmove();
{
current_a[i] = current_a[i+1];
}
current_a[5] = tempcur;
for (int ijk=0;ijk<=5; ijk++)
{
temp = temp + current_a[ijk];
}
temp = (temp/6UL); 

  return temp;
}

// Return value in millivolts
uint16_t get_supply_voltage(void)
{
  uint32_t vcc_adc;
  
  // Get raw VCC reading (through voltage divider of 22k/4.7k)
  vcc_adc = analogRead(VCC);
  
  // Convert 10-bit ADC reading to tenths of volts
  // Voltage divider is 4.7k and 22k
  //return ((vcc_adc * ANALOG_REF / 1024UL) * 267UL) / 47UL;

  // Convert 12-bit ADC reading to tenths of volts
  // Voltage divider is 4.7k and 22k
  return ((vcc_adc * ANALOG_REF / 4096UL) * 267UL) / 47UL;
}

void set_wpm(uint32_t new_wpm)
{
  // This is WPM * 1000 due to need for fractional WPM for slow modes
  //
  // Dit length in milliseconds is 1200 ms / WPM
  dit_length = (1200000UL / new_wpm);
}

uint32_t get_msg_delay(uint8_t delay_minutes)
{
  // The single function parameter is the message delay time in minutes
  if(delay_minutes > MAX_MSG_DELAY)
  {
    delay_minutes = MAX_MSG_DELAY;
  }

  // Number of clock ticks is the number of minutes * 60000 ticks/per min
  return delay_minutes * 60000UL;
}

void init_tx(void)
{
  if(tx_enable)
  {
    tx_reset();

    if(cur_mode == MODE_WSPR || cur_mode == MODE_JT65 || cur_mode == MODE_JT9 || cur_mode == MODE_JT4)
    {
      cur_state_end = cur_timer;
      cur_state = STATE_FSK;
    }
  }
}
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
void loop()
{
  char text[21];
  
  // Latch the current time
  // MUST disable interrupts during this read or there will be an occasional corruption of cur_timer
  noInterrupts();
  cur_timer = millis();
  interrupts();

  // Trigger WSPR
  if((cur_mode == MODE_WSPR || cur_mode == MODE_JT65 || cur_mode == MODE_JT9 || cur_mode == MODE_JT4) 
    && (gps.time.minute() % 6 == 0) && (gps.time.second() == 1))
  {
    init_tx();
  }
  
  if(tx)
  {
    si5351.set_clock_pwr(SI5351_CLK0, 1);
    si5351.set_clock_pwr(SI5351_CLK1, 1);
    digitalWrite(PIN_LED_TXL, LOW);
  }
  else
  {
    si5351.set_clock_pwr(SI5351_CLK0, 0);
    si5351.set_clock_pwr(SI5351_CLK1, 0);
    digitalWrite(PIN_LED_TXL, HIGH);
  }

  if(pa_enable)
  {
    digitalWrite(TX_KEY, HIGH);
  }
  else
  {
    digitalWrite(TX_KEY, LOW);
  }

  // State machine
  switch(cur_mode)
  {
  case MODE_DFCW3:
  case MODE_DFCW6:
  case MODE_DFCW10:
  case MODE_DFCW120:
  case MODE_QRSS3:
  case MODE_QRSS6:
  case MODE_QRSS10:
  case MODE_QRSS120:
  case MODE_CW:
    switch(cur_state)
    {
    case STATE_IDLE:
      // TX off
      if(cur_mode == MODE_CW)
      {
        pa_enable = false;
        tx = false;
      }
      else if(cur_mode == MODE_DFCW3 || cur_mode == MODE_DFCW6 || cur_mode == MODE_DFCW10 ||
        cur_mode == MODE_DFCW120)
      {
        pa_enable = true;
        tx = true;
      }
      else
      {
        pa_enable = true;
        tx = false;
      }

      tx_lock = false;
      
      if(tx_enable)
      {
        if(msg_delay > 0 && msg_delay_end <= cur_timer && cur_msg_p == msg_buffer && 
          (cur_mode == MODE_DFCW3 || cur_mode == MODE_DFCW6 || cur_mode == MODE_DFCW10 ||
          cur_mode == MODE_DFCW120))
        {
          //msg_delay_end = cur_timer + get_msg_delay(msg_delay);
          cur_state_end = cur_timer + (dit_length * MULT_WORDDELAY);
          cur_state = STATE_PREAMBLE;
          break;
        }

        msg_delay_end = cur_timer + get_msg_delay(msg_delay);
  
        // If this is the first time thru the message loop, get the first character
        if((cur_msg_p == msg_buffer) && (cur_character == '\0'))
        {
          cur_character = pgm_read_byte(&morsechar[(*cur_msg_p) - MORSE_CHAR_START]);
        }
  
        // Get the current element in the current character
        if(cur_character != '\0')
        {
          if(cur_character == 0b10000000 || cur_character == 0b11111111)	// End of character marker or SPACE
          {
            // Set next state based on whether EOC or SPACE
            if(cur_character == 0b10000000)
            {
              cur_state_end = cur_timer + (dit_length * MULT_DAH);
              cur_state = STATE_DAHDELAY;
              
              // Grab next character, set state to inter-character delay
              cur_msg_p++;
    
              // If we read a NULL from the announce buffer, set cur_character to NULL,
              // otherwise set to correct morse character
              if((*cur_msg_p) == '\0')
              {
                cur_character = '\0';
              }
              else
              {
                cur_character = pgm_read_byte(&morsechar[(*cur_msg_p) - MORSE_CHAR_START]);
              }
            }
            else
            {
              cur_state_end = cur_timer + (dit_length * MULT_WORDDELAY);
              cur_state = STATE_WORDDELAY;
            }
  
            // Grab next character, set state to inter-character delay
            //cur_msg_p++;
  
            /*
            // If we read a NULL from the announce buffer, set cur_character to NULL,
            // otherwise set to correct morse character
            if((*cur_msg_p) == '\0')
            {
              cur_character = '\0';
            }
            else
            {
              cur_character = pgm_read_byte(&morsechar[(*cur_msg_p) - MORSE_CHAR_START]);
            }
            */
          }
          else
          {
            // Mask off MSb, set cur_element
            if((cur_character & 0b10000000) == 0b10000000)
            {
              cur_state_end = cur_timer + (dit_length * MULT_DAH);
              cur_state = STATE_DAH;
            }
            else
            {
              cur_state_end = cur_timer + dit_length;
              cur_state = STATE_DIT;
            }
  
            // Shift left to get next element
            cur_character = cur_character << 1;
          }
        }
        else
        {
          // Reload the message buffer and set buffer pointer back to beginning
          switch(cur_buffer)
          {
          case BUFFER_0:
          default:
            strcpy(msg_buffer, flash_config.callsign);
            break;
          case BUFFER_1:
            strcpy(msg_buffer, flash_config.msg_mem_1);
            break;
          case BUFFER_2:
            strcpy(msg_buffer, flash_config.msg_mem_2);
            break;
          case BUFFER_3:
            strcpy(msg_buffer, flash_config.msg_mem_3);
            break;
          case BUFFER_4:
            strcpy(msg_buffer, flash_config.msg_mem_4);
            break;
          }
          cur_msg_p = msg_buffer;
          cur_character = '\0';
  
          if(msg_delay == 0)
          {
            // If a constantly repeating message, put a word delay at the end of message
            cur_state_end = cur_timer + (dit_length * MULT_WORDDELAY);
            cur_state = STATE_EOMDELAY;
          }
          else
          {
            // Otherwise, set the message delay time
            if(msg_delay_end < (cur_timer + (dit_length * MULT_WORDDELAY)))
            {
              cur_state_end = cur_timer + (dit_length * MULT_WORDDELAY);
            }
            else
            {
              cur_state_end = msg_delay_end;
            }
            
    	      cur_state = STATE_MSGDELAY;
          }
        }
      }
      break;

    case STATE_PREAMBLE:
      // Wait a word delay with TX on before starting message
      si5351.set_freq(frequency * 100ULL, 0, SI5351_CLK0);
  
      // Transmitter on
      pa_enable = true;
      tx = true;
      tx_lock = true;
      
      // When done waiting, go back to IDLE state to start the message
      if(cur_timer > cur_state_end)
      {
        cur_state = STATE_IDLE;
      }
      break;
  
    case STATE_DIT:
    case STATE_DAH:
      pa_enable = true;
      tx = true;
      tx_lock = true;
      
      switch(cur_mode)
      {
      case MODE_DFCW3:
      case MODE_DFCW6:
      case MODE_DFCW10:
      case MODE_DFCW120:
        // Set FSK to MARK
        si5351.set_freq((frequency + dfcw_offset) * 100ULL , 0, SI5351_CLK0);
        break;
      case MODE_QRSS3:
      case MODE_QRSS6:
      case MODE_QRSS10:
      case MODE_QRSS120:
      case MODE_CW:
        // Set FSK to 0
        si5351.set_freq(frequency * 100ULL, 0, SI5351_CLK0);
        break;
      default:
        break;
      }

      if(cur_timer > cur_state_end)
      {
        switch(cur_mode)
        {
        case MODE_DFCW3:
        case MODE_DFCW6:
        case MODE_DFCW10:
        case MODE_DFCW120:
          // Transmitter on
          pa_enable = true;
          tx = true;

          // Set FSK to 0
          si5351.set_freq(frequency * 100ULL, 0, SI5351_CLK0);
          break;
        case MODE_QRSS3:
        case MODE_QRSS6:
        case MODE_QRSS10:
        case MODE_QRSS120:
          // Transmitter off
          pa_enable = true;
          tx = false;

          // Set FSK to 0
          si5351.set_freq(frequency * 100ULL, 0, SI5351_CLK0);
          break;
        case MODE_CW:
          // Transmitter off
          pa_enable = false;
          tx = false;

          // Set FSK to 0
          si5351.set_freq(frequency * 100ULL, 0, SI5351_CLK0);
          break;
        default:
          break;
        }

        cur_state_end = cur_timer + dit_length;
        cur_state = STATE_DITDELAY;
      }
      break;
    case STATE_DITDELAY:
    case STATE_DAHDELAY:
    case STATE_WORDDELAY:
    case STATE_MSGDELAY:
    case STATE_EOMDELAY:
      tx_lock = true;
      // Set FSK to 0
      si5351.set_freq(frequency * 100ULL, 0, SI5351_CLK0);

      if(cur_state == STATE_MSGDELAY || cur_mode == MODE_QRSS3 || cur_mode == MODE_QRSS6 || cur_mode == MODE_QRSS10 || cur_mode == MODE_QRSS120 || cur_mode == MODE_CW)
      {
        // Transmitter off
        if(cur_mode == MODE_CW)
        {
          pa_enable = false;
        }
        else
        {
          pa_enable = true;
        }
        tx = false;
      }
      else
      {
        // Transmitter on
        pa_enable = true;
        tx = true;
      }

      if(cur_timer > cur_state_end)
      {
        if(cur_state == STATE_WORDDELAY)
        {
          // Grab next character
          cur_msg_p++;
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

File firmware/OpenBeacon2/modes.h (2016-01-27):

/*
 * modes.h
 *
 *  Created on: Jan 16, 2012
 *     Author: Jason Milldrum
 *     Company: Etherkit
 *
 *     Copyright (c) 2012, Jason Milldrum
 *     All rights reserved.
 *
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
 *  - Neither the name of Etherkit nor the names of its contributors may be
 *  used to endorse or promote products derived from this software without specific
 *  prior written permission.
 *
 *  THIS SOFTWARE IS PROVIDED BY THE COPYRIGHT HOLDERS AND CONTRIBUTORS "AS IS" AND ANY
 *  EXPRESS OR IMPLIED WARRANTIES, INCLUDING, BUT NOT LIMITED TO, THE IMPLIED WARRANTIES
 *  OF MERCHANTABILITY AND FITNESS FOR A PARTICULAR PURPOSE ARE DISCLAIMED. IN NO EVENT
 *  SHALL THE COPYRIGHT HOLDER OR CONTRIBUTORS BE LIABLE FOR ANY DIRECT, INDIRECT,
 *  INCIDENTAL, SPECIAL, EXEMPLARY, OR CONSEQUENTIAL DAMAGES (INCLUDING, BUT NOT LIMITED
 *  TO, PROCUREMENT OF SUBSTITUTE GOODS OR SERVICES; LOSS OF USE, DATA, OR PROFITS; OR
 *  BUSINESS INTERRUPTION) HOWEVER CAUSED AND ON ANY THEORY OF LIABILITY, WHETHER IN
 *  CONTRACT, STRICT LIABILITY, OR TORT (INCLUDING NEGLIGENCE OR OTHERWISE) ARISING IN
 *  ANY WAY OUT OF THE USE OF THIS SOFTWARE, EVEN IF ADVISED OF THE POSSIBILITY OF SUCH DAMAGE.
 */

#ifndef MODES_H_
#define MODES_H_

#include <stdint.h>

#define MODE_COUNT			        16

#define MSG_BUFFER_SIZE			    41			// Message size in characters (+1 for \0)
#define WSPR_BUFFER_SIZE		    163			// WSPR symbol buffer size, 162 symbols plus '\0'
#define GLYPH_SIZE				      23			// Maximum size of custom glyph in columns (+1 for \0)
#define MAX_MSG_DELAY			      30			// Maximum message delay time in minutes
#define MAX_WPM					        50
#define MAX_NUM_GLYPH			      2

#define WSPR_TONE_SPACING       146
#define WSPR_SYMBOL_LENGTH      683         // 683 ms symbol length
#define JT65_TONE_SPACING       269
#define JT65_SYMBOL_LENGTH      372         // 372 ms symbol length
#define JT9_TONE_SPACING        174
#define JT9_SYMBOL_LENGTH       576         // 576 ms symbol length
#define JT4_TONE_SPACING        437
#define JT4_SYMBOL_LENGTH       229         // 229 ms symbol length
//#define SYMBOL_COUNT            WSPR_SYMBOL_COUNT

enum MODE {MODE_DFCW3, MODE_DFCW6, MODE_DFCW10, MODE_DFCW120, MODE_QRSS3, MODE_QRSS6, MODE_QRSS10, MODE_QRSS120,
  MODE_CW, MODE_HELL, MODE_WSPR, MODE_JT65, MODE_JT9, MODE_JT4, MODE_GLYPHCODE, MODE_CAL};

// Array of mode names, indexed to enum MODE
char mode_list[MODE_COUNT][10] = 
{"DFCW3", "DFCW6", "DFCW10", "DFCW120", "QRSS3", "QRSS6", "QRSS10", "QRSS120", "CW", "HELL", "WSPR", 
  "JT65", "JT9", "JT4", "GLYPH", "CAL"};

#if OPENBEACON_CLIENT

const char mode_desc[MODE_COUNT][100] =
{ "Dual Frequency CW - 3 second dits",
  "Dual Frequency CW - 6 second dits",
  "Dual Frequency CW - 10 second dits",
  "Dual Frequency CW - 120 second dits",
  "QRSS - 3 second dits",
  "QRSS - 6 second dits",
  "QRSS - 10 second dits",
  "QRSS - 120 second dits",
  "CW",
  "Sequential Multi-tone Hell",
  "WSPR",
  "JT65",
  "JT9",
  "JT4",
  "Glyphcode",
  "Calibration"
 };
#endif

// Array of speeds for the modes, indexed to enum MODE
// Speeds are in WPM * 1000
const uint16_t dit_speed[MODE_COUNT] = {400, 200, 120, 10, 400, 200, 120, 10, 35000, 3500, 1750, 1750, 1750, 1750, 4000, 10000};

#endif /* MODES_H_ */
